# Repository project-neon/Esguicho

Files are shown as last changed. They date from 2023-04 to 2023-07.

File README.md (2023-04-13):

# Esguicho

## Arquivos

  Neste repositório temos os principais arquivos que usamos para os 3 capítulos, Eletrônica, Mecânica e Software. Segue abaixo uma lista do que temos em cada uma das pastas:

  ### Electronics
    Na parte eletrônica, utilizamos o programa Kicad que é open source e permite a criação e edição de PCBs.
    Caso queira editar ou vizualizar o projeto, clone o diretório "Eletronics", pois nele está contido o esquemático 
    no formato PDF e sch,  a PCB no formato pcb e os arquivos pro e plr próprios do Kicad.
    
  ### Mechanics
    Na pasta da mecânica, há arquivos no formato step e stl para que possam ser utilizados para visualização 
    e manufatura 3D, juntamente com os arquivos pdf dos desenhos técnicos para melhor compreensão do projeto
    
  ### Software
    Nesta pasta deixamos todos os arquivos que formam o código do robô. Então .ino e .h são os principais arquivos.
    Usamos os .h's para segmentar o código e não ser um único bloco enorme, dividindo eles de acordo com sua funcionalidade.
    O .ino é onde fica a base de todo o código, como o setup() e o loop(). Temos os códigos de testes e o código autonomous
    que usamos durante as lutas oficiais.

## Fluxo Git
- Quando for acrescentar uma feature (um comportamento novo para o robô), crie uma brancha chamada `feat/nome-da-feature`
- Quando for corrir algum bug no código, crie uma brancha chamada `fix/nome-do-fix`
- Quando for adicionar novos arquivos na mecância ou eletrônica, crie uma brancha chamada `update/eletronics-<data>` ou `update/mechanis-<data>`, exemplo: `update/eletronics-01-04-2023`
- A partir da main: `git checkout -b nome-da-branch`, ex: `git checkout -b feat/novos-testes`

## Na hora de fazer o commit
- Nomeie o seu commit primeiro dizendo o que foi feito, ex: `fix: `, `feat: ` ou `update: `
- Você pode adicionar no assunto (comentário) ou na mensagem do commit também onde que a mudança foi feita.
- `git push`

Para saber mais de commits, você pode acessar esse [link](https://www.freecodecamp.org/news/how-to-write-better-git-commit-messages/)

## Na hora de fazer o merge
- Depois de subir o commit, crie um PR (Pull Request) e peça pro resto do pessoal da equipe dar uma conferida antes de ser aprovado



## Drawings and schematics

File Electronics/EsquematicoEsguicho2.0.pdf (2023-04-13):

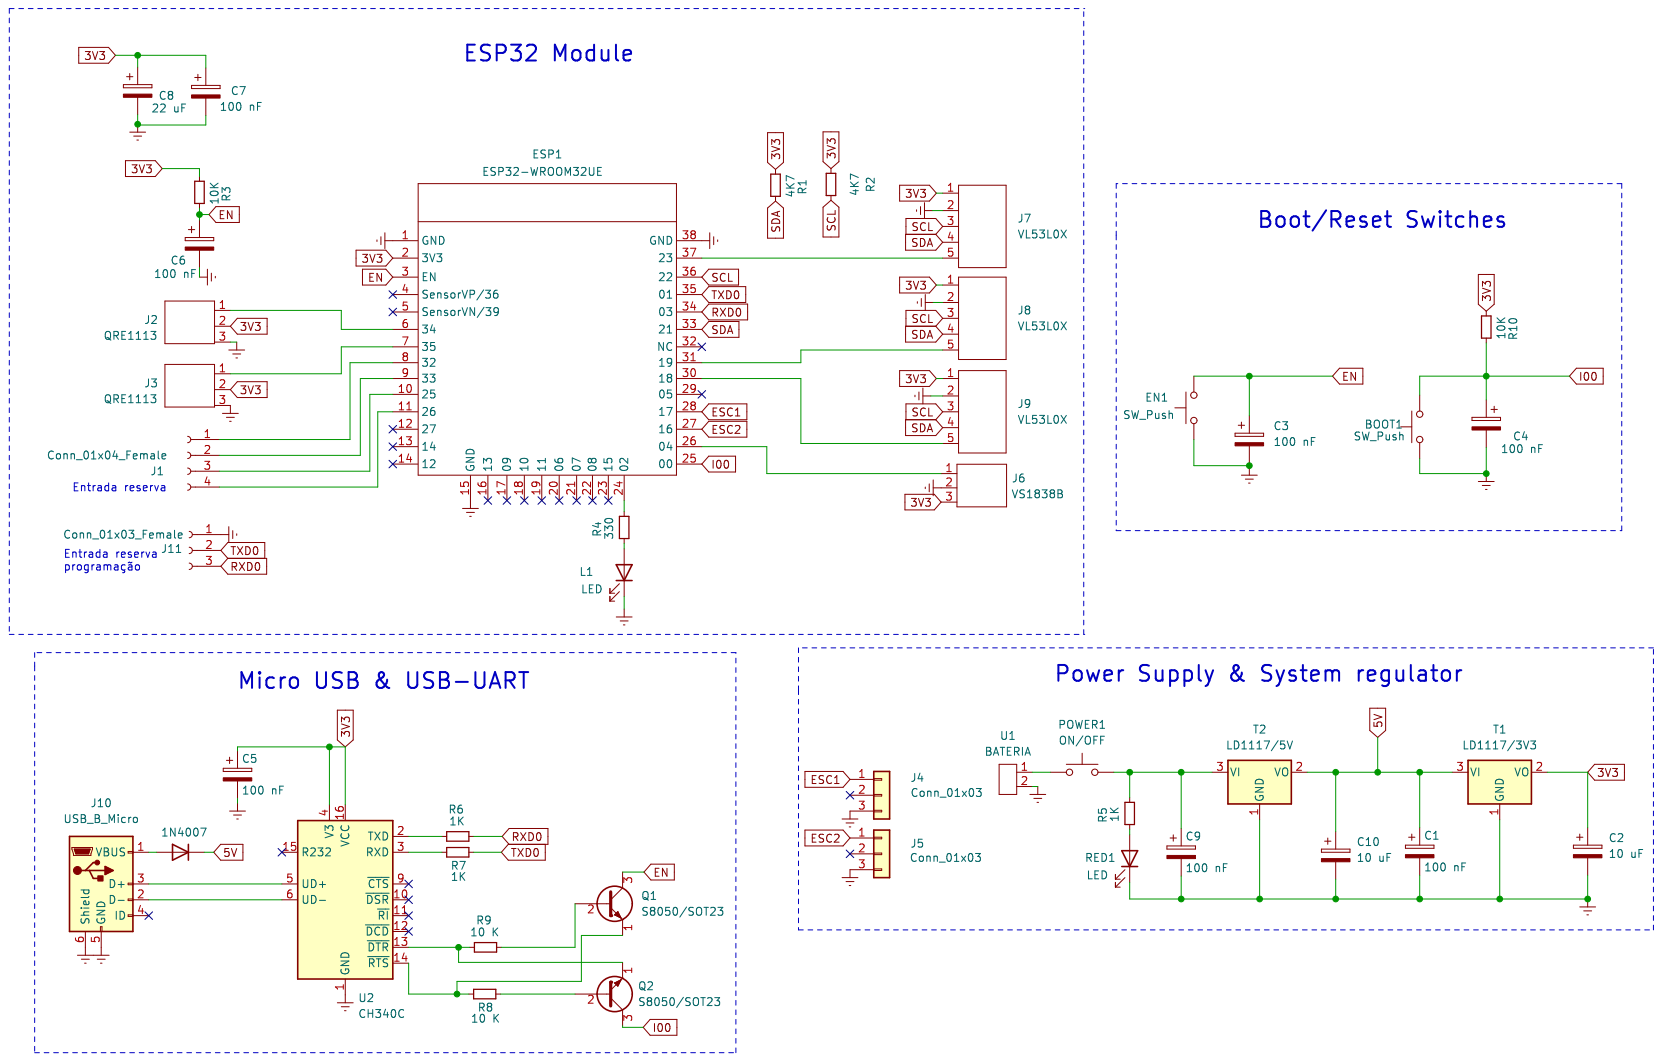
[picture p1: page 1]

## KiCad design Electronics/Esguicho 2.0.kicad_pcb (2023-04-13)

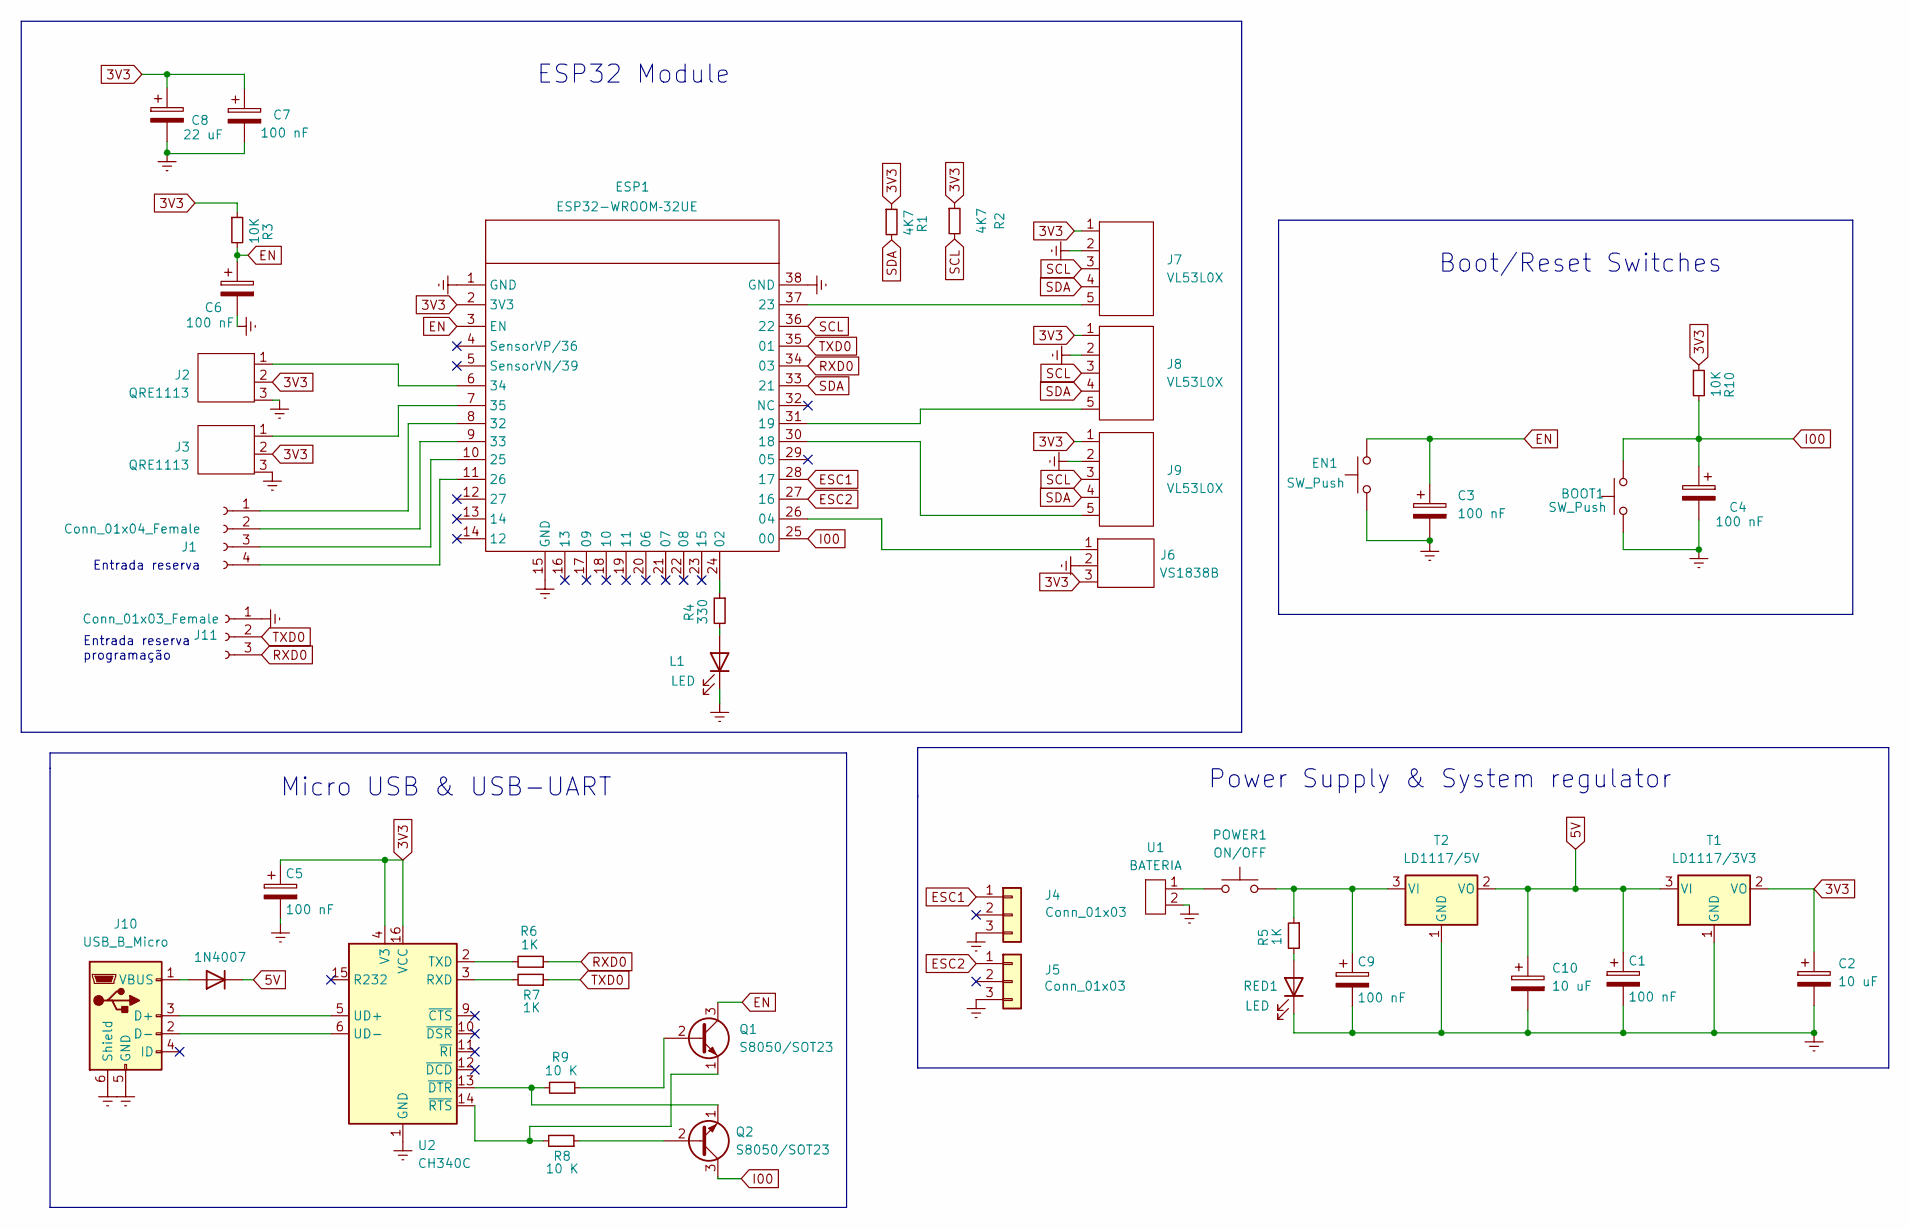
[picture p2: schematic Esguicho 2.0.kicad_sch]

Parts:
BOOT1: SW_Push; SW_SPST_TL3305A
C1, C3, C4, C5, C6, C7, C9: 100 nF; C_0603_1608Metric
C2, C10: 10 uF; C_0603_1608Metric
C8: 22 uF; C_0603_1608Metric
D1: 1N4007; D_SMA
EN1: SW_Push; SW_SPST_TL3305A
ESP1: ESP32-WROOM­32UE; ESP32-WROOM-32
J1: Conn_01x04_Female; PinSocket_1x04_P2.54mm_Vertical
J2, J3: QRE1113; JST_PH_S3B-PH-K_1x03_P2.00mm_Horizontal
J4, J5: Conn_01x03; JST_XH_B3B-XH-AM_1x03_P2.50mm_Vertical
J6: VS1838B; JST_ZE_B03B-ZESK-1D_1x03_P1.50mm_Vertical
J7, J8, J9: VL53L0X; JST_PH_S5B-PH-K_1x05_P2.00mm_Horizontal
J10: USB_B_Micro; USB_Micro-B_Amphenol_10118194_Horizontal
J11: Conn_01x03_Female; PinSocket_1x03_P2.54mm_Vertical
L1: LED; LED_0603_1608Metric
POWER1: ON/OFF; Nidec_Copal_SH-7010C
Q1, Q2: S8050/SOT23; SOT-23
R1, R2: 4K7; R_0603_1608Metric
R3, R10: 10K; R_0603_1608Metric
R4: 330; R_0603_1608Metric
R5, R6, R7: 1K; R_0603_1608Metric
R8, R9: 10 K; R_0603_1608Metric
RED1: LED; LED_0603_1608Metric
T1: LD1117/3V3; SOT-223-3_TabPin2
T2: LD1117/5V; SOT-223-3_TabPin2
U1: BATERIA; JST_XH_B2B-XH-AM_1x02_P2.50mm_Vertical
U2: CH340C; SOIC-16_3.9x9.9mm_P1.27mm

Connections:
3V3: C2.1, C5.1, C7.1, C8.1, ESP1.2 (3V3), J2.2, J3.2, J6.3, J7.1, J8.1, J9.1, R1.1, R2.1, R3.1, R10.1, T1.2 (VO), U2.4 (V3), U2.16 (VCC)
5V: C1.1, C10.1, D1.1 (K), T1.3 (VI), T2.2 (VO)
EN: C3.1, C6.1, EN1.1, ESP1.3 (EN), Q1.3 (C), R3.2
ESC1: ESP1.28 (17), J4.1
ESC2: ESP1.27 (16), J5.1
GNDREF: BOOT1.2, C1.2, C2.2, C3.2, C4.2, C5.2, C6.2, C7.2, C8.2, C9.2, C10.2, EN1.2, ESP1.1 (GND), ESP1.15 (GND), ESP1.38 (GND), J2.3, J3.3, J4.3, J5.3, J6.2, J7.2, J8.2, J9.2, J10.5 (GND), J10.6 (Shield), J11.1, L1.1 (K), RED1.1 (K), T1.1 (GND), T2.1 (GND), U1.2, U2.1 (GND)
I00: BOOT1.1, C4.1, ESP1.25 (00), Q2.3 (C), R10.2
unnamed: C9.1, POWER1.2, POWER1.8, R5.1, T2.3 (VI)
unnamed: D1.2 (A), J10.1 (VBUS)
unnamed: ESP1.6 (34), J2.1
unnamed: ESP1.7 (35), J3.1
unnamed: ESP1.8 (32), J1.1
unnamed: ESP1.9 (33), J1.2
unnamed: ESP1.10 (25), J1.3
unnamed: ESP1.11 (26), J1.4
unnamed: ESP1.24 (02), R4.1
unnamed: ESP1.26 (04), J6.1
unnamed: ESP1.30 (18), J9.5
unnamed: ESP1.31 (19), J8.5
unnamed: ESP1.37 (23), J7.5
unnamed: J10.2 (D-), U2.6 (UD-)
unnamed: J10.3 (D+), U2.5 (UD+)
unnamed: L1.2 (A), R4.2
unnamed: POWER1.1, POWER1.4, U1.1
unnamed: Q1.1 (E), R8.2, U2.14 (~RTS)
unnamed: Q1.2 (B), R9.1
unnamed: Q2.1 (E), R9.2, U2.13 (~DTR)
unnamed: Q2.2 (B), R8.1
unnamed: R5.2, RED1.2 (A)
unnamed: R6.2, U2.2 (TXD)
unnamed: R7.2, U2.3 (RXD)
RXD0: ESP1.34 (03), J11.3, R6.1
SCL: ESP1.36 (22), J7.3, J8.3, J9.3, R2.2
SDA: ESP1.33 (21), J7.4, J8.4, J9.4, R1.2
TXD0: ESP1.35 (01), J11.2, R7.1

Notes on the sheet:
Entrada reserva
Micro USB & USB-UART
Boot/Reset Switches
Entrada reserva programação
ESP32 Module
Power Supply & System regulator

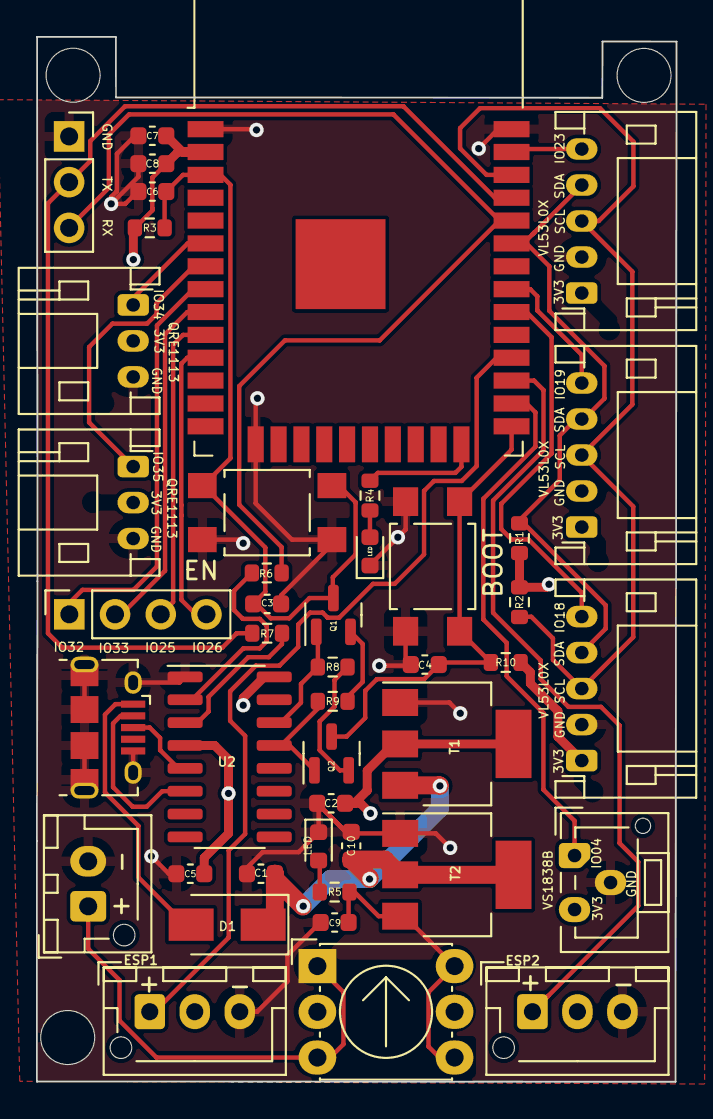
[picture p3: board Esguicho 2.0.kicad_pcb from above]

Board: 2 copper layers, 35.5 x 58.0 mm, 45 parts (1 on the bottom side), 35 nets.

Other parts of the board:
G: LOGO; Logo.Neon

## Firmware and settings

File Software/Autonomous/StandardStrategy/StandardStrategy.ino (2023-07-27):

//Bibliotecas internas
#include "config.h"
#include "constants_declaration.h"
#include "controller_IR.h"
#include "motors.h"
#include "distance_sensors.h"
#include "utils.h"

int flag = 0; //Direita --> 1, Esquerda --> -1, Valor inicial --> 0

void setup(){
  Serial.begin(115200);

  controllerInit();
  sensorsInit();
  motorsInit();
}

bool needsToStop(bool newSpeedLPositive, bool newSpeedRPositive ) {
  if (speedL == 0 and speedR == 0) return false; //Se a vel é 0, pode ir pra frente ou trás sem parar

  speedLPositive = speedL > 5 ? true : false; //Adicionei uma margem para ficar de acordo com a de 84 ate 94 que vai pra esc
  speedRPositive = speedR > 5 ? true : false;
  if ((speedLPositive == newSpeedLPositive) and (speedRPositive == newSpeedRPositive)) {
    if (fluctuationsCounter > 0) fluctuationsCounter--; //Pode ser que a gnt soh teve variacoes temporarias, entao a gnt vai tirando elas
    return false; //Se o sentido q vai rodar é igual ao anterior, nao para!
  }

  fluctuationsCounter++;
  if (fluctuationsCounter >= 3) {
    speedL = speedR = 0; // APenas para caso a gnt tenha tido flutuacoes seguidas o suficiente. 10 eh o bastante?
    motorsOutput();
    delay(10); //TODO: Podemos aumentar esse valor p/ ver no codigo mais claramente se ele para antes de mudar a direcao
    fluctuationsCounter = 0;
    return false; //Retorna falso para o codigo nao fazer um return dentro do loop!
  }
  return true;

}

void loop() {

  controllerIR();
  distanceRead();

//////////////////////////////Led Ligado//////////////////////////////
  if(stage == 1) {
    digitalWrite(2, HIGH);
//////////////////////////////Estrategia//////////////////////////////
  } else if(stage == 2) {
   if(distC < distAtk/3 and (distL < distAtk/3 or distR < distAtk/3)) {
      if (needsToStop(true,true)) return;
      Serial.print("ATACANDO MÁX \t\t");
      speedL = speedR = speedAtk;
    } else if(distC < distAtk and (distL < distAtk or distR < distAtk)) {
      if (needsToStop(true,true)) return;
      Serial.print("ATACANDO \t\t");
      speedL = speedR = speedStandard;
    } else if (distL < distAtk or distR < distAtk) {
      if (needsToStop(true,true)) return;
      (distL < distAtk) ? Serial.print("ESQ \t\t") : Serial.print("DIR \t\t");
      speedL = (distL < distAtk) ? speedStandard*0.9 : speedStandard;
      speedR = (distL < distAtk) ? speedStandard : speedStandard*0.9;
      flag = (distL < distAtk) ? -1 : 1;
    } else {
      if (needsToStop(flag != -1, flag == -1)) return;
      (flag == -1) ? Serial.print("PROCURANDO ESQ \t\t") :  Serial.print("PROCURANDO DIR \t\t");
      speedL = (flag == -1) ? -1*searchSpeed : searchSpeed;
      speedR = (flag == -1) ? searchSpeed : -1*searchSpeed;
    }
//////////////////////////////Robo Parou//////////////////////////////
  } else {
    speedL = speedR = 0;
  }

  motorsOutput();
  printSpeed();
  printDistances();

}

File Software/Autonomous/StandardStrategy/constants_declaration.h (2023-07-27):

const int distMax = 600;  //Distância máxima permitida como referência para os sensores (em milímetros)
const int distAtk = 600;
const int distAtkMax = 200;

const int speedMax = 85; //vel max para ser usada durande o ataque
const int speedStandard = 25; //vel padrão --- Cuidado se abaixar para menos de
const int speedAtk = 70; //vel padrão --- Cuidado se abaixar para menos de 30!!!
const int searchSpeed = 10;//vel de girar no proprio eixo

int fluctuationsCounter = 0;

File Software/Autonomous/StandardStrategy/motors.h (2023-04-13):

#include <ESP32Servo.h> //Comunicação com a ESC de cada motor v0.11.0

//Cria os objetos para  cada ESC
Servo ESCL; //ESC que controla o motor da esquerda
Servo ESCR; //ESC que controla o motor da direita

//Variáveis que receberão o valor da velocidades que serão enviadas para os ESC's
int speedL = 0; //Valor de velocidade da esquerda
int speedR = 0; //Valor de velocidade da direita

int EscSpeedL = 0; //Valor de velocidade para o ESC da esquerda
int EscSpeedR = 0; //Valor de velocidade para o ESC da direita

bool speedLPositive = true; //Valor de velocidade para o ESC da esquerda
bool speedRPositive = true; //Valor de velocidade para o ESC da direita

int motorUnbiasedVel = 92; //Velocidade 0 da ESC

void motorsInit() {
    //Configurando o sinal PWM que será enviado aos ESC's
    ESCL.setPeriodHertz(50);             // Estabelece a frequência do PWM (50Hz)
    ESCL.attach(MOTOR_L, 1000,2000);     // (Pino onde será enviado o sinal, largura de pulso mínima, largura de pulso máxima)
    ESCR.setPeriodHertz(50);
    ESCR.attach(MOTOR_R, 1000,2000);
    /*
    * É necessário estabelecer uma faixa de largura de pulso para que o ESC
    * responda corretamente a variação do sinal analógico lido do potenciômetro
    * O valor da largura de pulso deve ser informado na escala de micro-segundos
    * No caso, a largura de pulso do PWM mínima é de 1000us e a máxima é de 2000us
    */
    ESCL.write(motorUnbiasedVel);
    ESCR.write(motorUnbiasedVel);
}

void motorsOutput() {
    EscSpeedL = map(speedL, -100, 100, 0, 180);
    EscSpeedR = map(speedR, -100, 100, 0, 180);

    if (EscSpeedL > 84 and EscSpeedL < 94) EscSpeedL = motorUnbiasedVel;
    if (EscSpeedR > 84 and EscSpeedR < 94) EscSpeedR = motorUnbiasedVel;

    ESCL.write(EscSpeedL);
    ESCR.write(EscSpeedR);
}

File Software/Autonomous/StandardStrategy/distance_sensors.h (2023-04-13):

#include <VL53L0X.h>    //sensores de distância v1.3.1

//Cria os objetos para cada sensor
VL53L0X sensorL;  //Sensor da esquerda
VL53L0X sensorC;  //Sensor da frente
VL53L0X sensorR;  //Sensor da direita

//Variáveis que vão receber os valores lidos dos pinos dos sensores
int distL;  //Valor lido pelo sensor da esquerda
int distC;  //Valor lido pelo sensor da frente
int distR;  //Valor lido pelo sensor da direita

void sensorsInit() {
    pinMode(SDIST_L, OUTPUT);
    pinMode(SDIST_C, OUTPUT);
    pinMode(SDIST_R, OUTPUT);

    digitalWrite(SDIST_L, LOW);
    digitalWrite(SDIST_C, LOW);
    digitalWrite(SDIST_R, LOW);

    pinMode(SDIST_L, INPUT);
    sensorL.init(true);
    sensorL.setAddress((uint8_t)0x21); //endereço do sensor da esquerda

    pinMode(SDIST_C, INPUT);
    sensorC.init(true);
    sensorC.setAddress((uint8_t)0x23); //endereço do sensor da frente

    pinMode(SDIST_R, INPUT);
    sensorR.init(true);
    sensorR.setAddress((uint8_t)0x25); //endereço do sensor da direita

    sensorL.setTimeout(100);
    sensorC.setTimeout(100);
    sensorR.setTimeout(100);
}

void distanceRead() {
    //Armazena os valores lidos nas respectivas variáveis
    distL = sensorL.readRangeSingleMillimeters();
    distC = sensorC.readRangeSingleMillimeters();
    distR = sensorR.readRangeSingleMillimeters();
    if(stage == 0){
        if((distL > 60000) or (distC > 60000) or (distR > 60000)) {
        digitalWrite(2, HIGH);
        }
        else{
        digitalWrite(2, LOW);
        }
    }

    if(distL > 600) distL = 600;
    if(distC > 600) distC = 600;
    if(distR > 600) distR = 600;
}

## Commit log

2022-09-21 Starting the main code
    - Por enquanto, estou deixando simples, então nós não recebemos os comandos do controle do Juiz e qual estratégia que o robô vai usar é escrita dentro do código
    - Comecei a lógica de escolhe de estratégia, separando a estratégia do loop e fazendo um Switch Case
2022-10-01 fix: mudança do nome.ino para alinhar com o nome da pasta
2022-10-01 feat: Edge sensors test
2022-10-01 fix: edge sensors test
    [TESTE-SENSOR-BORDA.ino]
2022-10-08 fix: variavel de controle da vel geral
2022-10-12 fix: teste IRremote funcionando
    [TESTE-IR.ino]
2022-10-12 fix: changing timer++ for millis()
2022-10-12 feat: codigo teste sensores de distancia
2022-10-15 feat: led pisca quando aperta 1
2023-01-10 feat: controller address Ana fix: simplifying code
    [TESTE-IR-CONTROLLER.ino]
2023-01-13 update: terminando de organizar o codigo
2023-01-16 fix: atualizações pós teste
    [constants_declaration.h, controller_IR.h, motors.h]
2023-01-18 feat: teste de tracao
2023-02-04 fix: valor inicia ESC, Vel Max, mudanca brupta vel
    [constants_declaration.h, motors.h]
2023-02-11 feat: teste geral para os motores
2023-02-11 remocao de testes de motores redundantes
2023-02-23 add: teste para a inspecao
2023-02-24 fix: teste de inspecao pos teste
    [TESTE-INSPECAO.ino]
2023-02-24 add: simplifica codigo parar robo antes de girar
2023-02-25 SIMPLIFICAO do codigo para a competicao
2023-03-18 fix: cleaning code for Pull Request
    [constants_declaration.h, controller_IR.h, distance_sensors.h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]
2023-03-18 fix: cleaning all trash code we don't use anymore
    [TESTE-2POT-BRUSHLESS.ino, TESTE-GERAL-MOTORES.ino, TESTE-IR-CONTROLLER.ino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]
2023-03-18 add: Eletronics files
    [Esguicho 2.0.kicad_pcb, Esguicho 2.0.kicad_sch]
2023-03-25 fix: organizing the code and chang PT to EN
    [SimpleStrategy.ino, StandardStrategy.ino, TESTE-GERAL-MOTORES.ino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]
2023-04-05 Add: Test Led-Blink Nesteru
2023-04-07 fix: _config.h name to only config.h
    [SimpleStrategy.ino, StandardStrategy.ino, TESTE-GERAL-MOTORES.ino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]
2023-04-07 fix: 3 strategies code - simple, 3Sensores, Standard
    [SimpleStrategy3Sensors.ino, StandardStrategy.ino, constants_declaration.h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]
2023-04-08 fix: distance read and pint 3Sensors Strategy
    [SimpleStrategy3Sensors.ino]
2023-05-26 fix: refinando o controle
    [SimpleStrategy3Sensors.ino, StandardStrategy.ino, constants_declaration.h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]
2023-05-26 fix: Electronics file name
    [Esguicho 2.0.kicad_pcb, Esguicho 2.0.kicad_sch]
2023-05-26 fix: IR sensor to Continuos mode update: Constants values, add: Middle Sensor
    [SimpleStrategy3Sensors.ino, StandardStrategy.ino, constants_declaration.h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]
